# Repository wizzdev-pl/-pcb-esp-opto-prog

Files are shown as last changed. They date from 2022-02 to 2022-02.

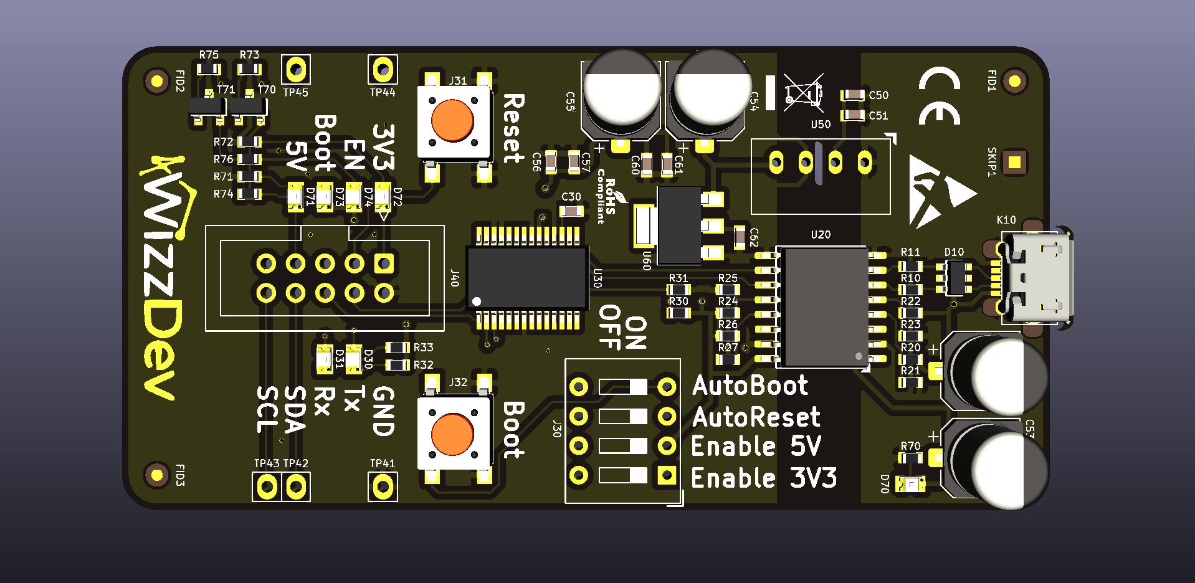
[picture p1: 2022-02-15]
Doc/EspOptoProg HV2 220111/EspOptoProg HV2 220111 Images/02 top.jpg

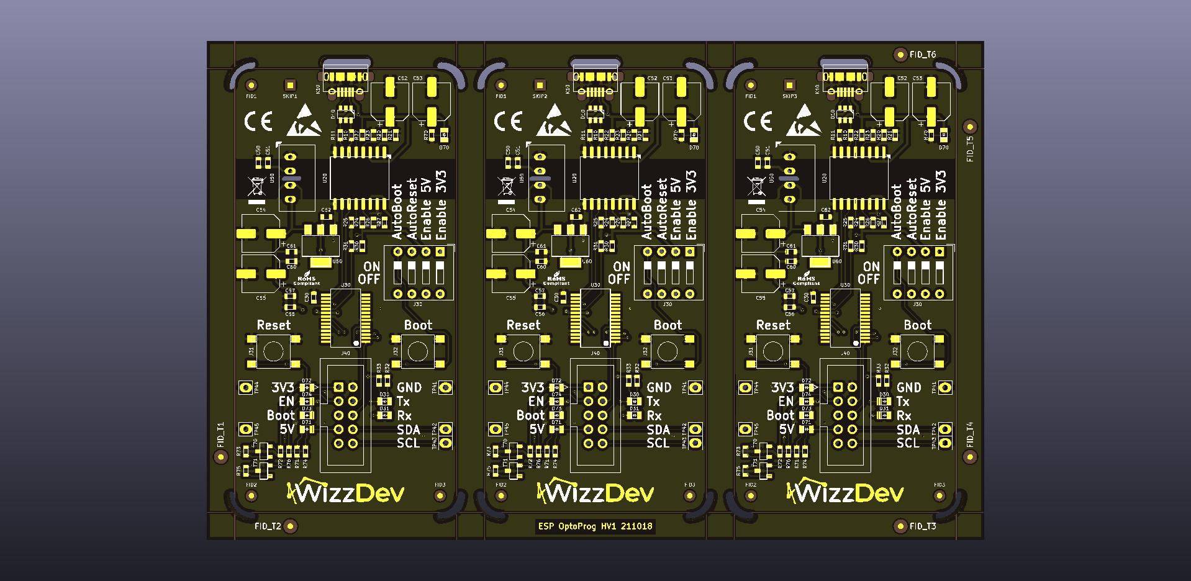
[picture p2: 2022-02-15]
Doc/EspOptoProg HV2 220111/EspOptoProg HV2 220111 Images/11 top.jpg

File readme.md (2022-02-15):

# ESP Optoisolated Programmer

This repo contains design files of the ESP Optoisolated Programmer. It is helpful to develop software for products with and ESP microcontroller that are powered from 230V mains. It works for ESP32, ESP8266 and all other ESP modules.

For detailed description please read:
- [Schematic Description 1](https://wizzdev.pl/blog/esp32-optoisolated-programmer-schematic-description-1/)
- [Schematic Description 2](https://wizzdev.pl/blog/esp32-optoisolated-programmer-schematic-description-2/)
- [PCB Analysis 1](https://wizzdev.pl/blog/esp32-optoisolated-programmer-pcb-analysis-1-2/)
- [PCB Analysis 2](https://wizzdev.pl/blog/esp32-optoisolated-programmer-pcb-analysis-2/)
- [PCB Analysis 3](https://wizzdev.pl/blog/esp32-optoisolated-programmer-pcb-analysis-3/)

To open and edit design files, please use Kicad 6.

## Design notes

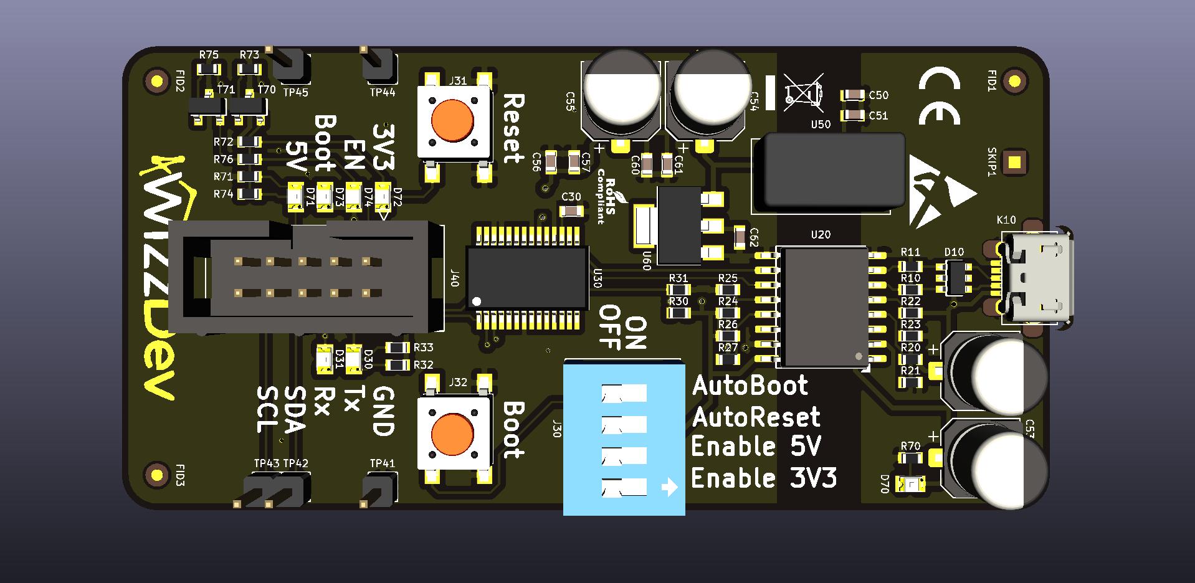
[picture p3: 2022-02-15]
Doc/EspOptoProg HV2 220111/EspOptoProg HV2 220111 Images/03 top.jpg

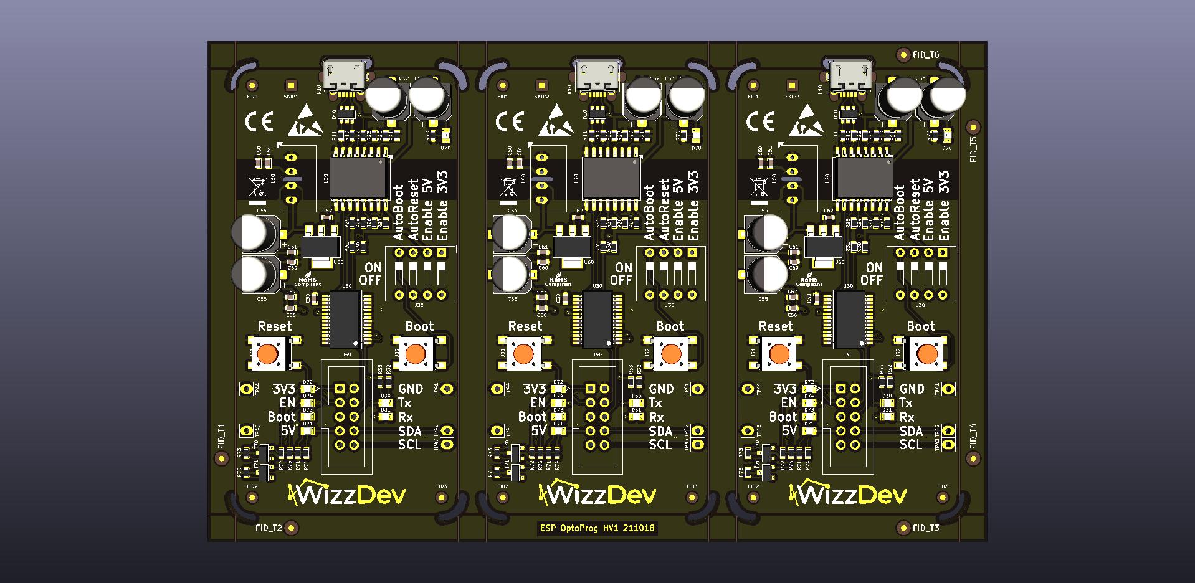
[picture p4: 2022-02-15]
Doc/EspOptoProg HV2 220111/EspOptoProg HV2 220111 Images/12 top.jpg

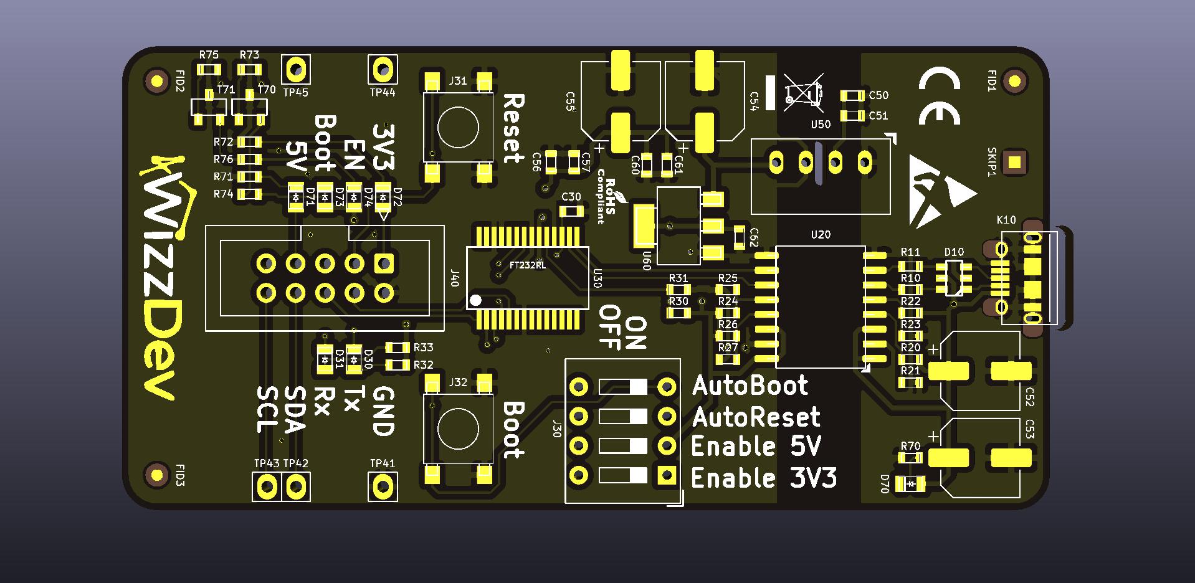
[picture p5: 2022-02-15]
Doc/EspOptoProg HV2 220111/EspOptoProg HV2 220111 Images/01 top.jpg

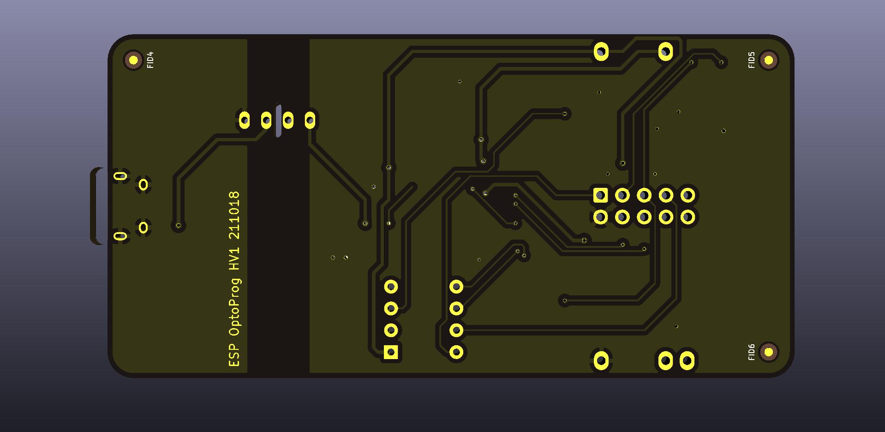
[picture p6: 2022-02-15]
Doc/EspOptoProg HV2 220111/EspOptoProg HV2 220111 Images/04 bottom.jpg

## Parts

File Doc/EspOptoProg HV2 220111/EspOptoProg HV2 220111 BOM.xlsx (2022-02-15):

Id | Ref | Package | Qty | Value | Comment | Link / part number
1 | U50 | AMxS-xxxxSZ | 1 | AM2S-0505SZ | Converter: DC/DC; 2W; Uin: 4.5÷5.5V; Uout: 5VDC; Iout: 400mA; SIP4
2 | C21,C20,C57,C62,C61,C50,C30 | C_0603 | 7 | 100n | Voltage min 25V, Tolerance 25%, X7R
5 | U20 | SOIC-16W_7.5x10.3mm_P1.27mm | 1 | ADUM3160 | IC: interface; digital isolator; 12Mbps; iCoupler®; 3÷5.5VDC; USB
7 | U30 | ssop-28 | 1 | FT232RL | IC: interface; USB-UART; Full Speed; 3.3÷5VDC; reel; SSOP28
8 | C53,C55,C54,C52 | CP_Elec_6.3x7.7 | 4 | 220u | Capacitor: electrolytic; SMD; 220uF; 10VDC; Ø6.3x7.7mm; ±20%; 2000h | https://www.tme.eu/pl/en/details/sc1a227m6l07kvr/85degc-smd-electrolytic-capacitors/samwha/
9 | J30 | SW_DIP_SPSTx04_Slide_9.78x12.34mm_W7.62mm_P2.54mm | 1 | DIPSW4 | Switch: DIP-SWITCH; Poles number: 4; ON-OFF; 0.1A/24VDC; Pos: 2 | https://www.tme.eu/pl/en/details/eah104e/dip-switches/diptronics/ndi-04h-v/
10 | J40 | IDC-Header_2x05_P2.54mm_Vertical | 1 | IDC-10 | Pin header; pin strips; male; PIN: 10; straight; 2.54mm; THT; 2x5
11 | C56,C51 | C_0603 | 2 | 10u | Voltage min 25V, Tolerance 25%, X7R
14 | T71,T70 | SOT23 | 2 | BC857 | Transistor: PNP; bipolar; 45V; 0.1A; 0.25W; SOT23
16 | R76,R74,R33,R32 | R_0603 | 4 | 100R | Tolerance 5%, Voltage min 25V, Power min 0.1W
17 | R75,R73,R31 | R_0603 | 3 | 10k | Tolerance 5%, Voltage min 25V, Power min 0.1W
18 | D74,D73 | LED_0805 | 2 | OF-SMD2012Y | LED; SMD; 0805; yellow; 210÷270mcd; 2x1.25x0.68mm; 120°; 1.8÷2V
22 | U60 | SOT223 | 1 | 1117-3.3 | Linear regulator, Output 3.3V, Current 1A, Package SOT223
23 | R72 | R_0603 | 1 | 1k | Tolerance 5%, Voltage min 25V, Power min 0.1W
24 | R71,R70 | R_0603 | 2 | 2k2 | Tolerance 5%, Voltage min 25V, Power min 0.1W
25 | R30 | R_0603 | 1 | 4k7 | Tolerance 5%, Voltage min 25V, Power min 0.1W
26 | R11,R10 | R_0603 | 2 | 22R | Tolerance 5%, Voltage min 25V, Power min 0.1W
27 | K10 | USB_Micro_B_Amphenol_10118194-0001LF_PIP | 1 | USB | Socket; USB B micro; on PCBs; SMT,THT; PIN: 5; horizontal; USB 2.0 | https://www.tme.eu/pl/en/details/10118194-0001lf_c/usb-ieee1394-connectors/amphenol-icc/10118194-0001lf/
28 | J32,J31 | TACT_6x6_SMD | 2 | TACT_6x6_SMD | Microswitch TACT; SPST-NO; Pos: 2; 0.05A/12VDC; SMT; none; 1.6N | https://www.tme.eu/pl/en/details/tactm-69n-f/microswitches-tact/ninigi/
34 | D72,D71,D70 | LED_0805 | 3 | OF-SMD2012W | LED; SMD; 0805; white cold; 1000÷1400mcd; 6500K; 120°; 20mA
35 | D31 | LED_0805 | 1 | OF-SMD2012G | LED; SMD; 0805; green; 50÷100mcd; 2x1.25x0.68mm; 120°; 1.8÷2V; 20mA
36 | D30 | LED_0805 | 1 | OF-SMD2012R | LED; SMD; 0805; red; 90÷120mcd; 2x1.25x0.68mm; 120°; 1.6÷1.9V; 20mA
37 | D10 | SOT23-6 | 1 | USBLC6-2 | Diode: TVS array; 6V; bidirectional; SOT23-6; Package: reel,tape
38 | C60 | C_0603 | 1 | 1u | Voltage min 25V, Tolerance 25%, X7R

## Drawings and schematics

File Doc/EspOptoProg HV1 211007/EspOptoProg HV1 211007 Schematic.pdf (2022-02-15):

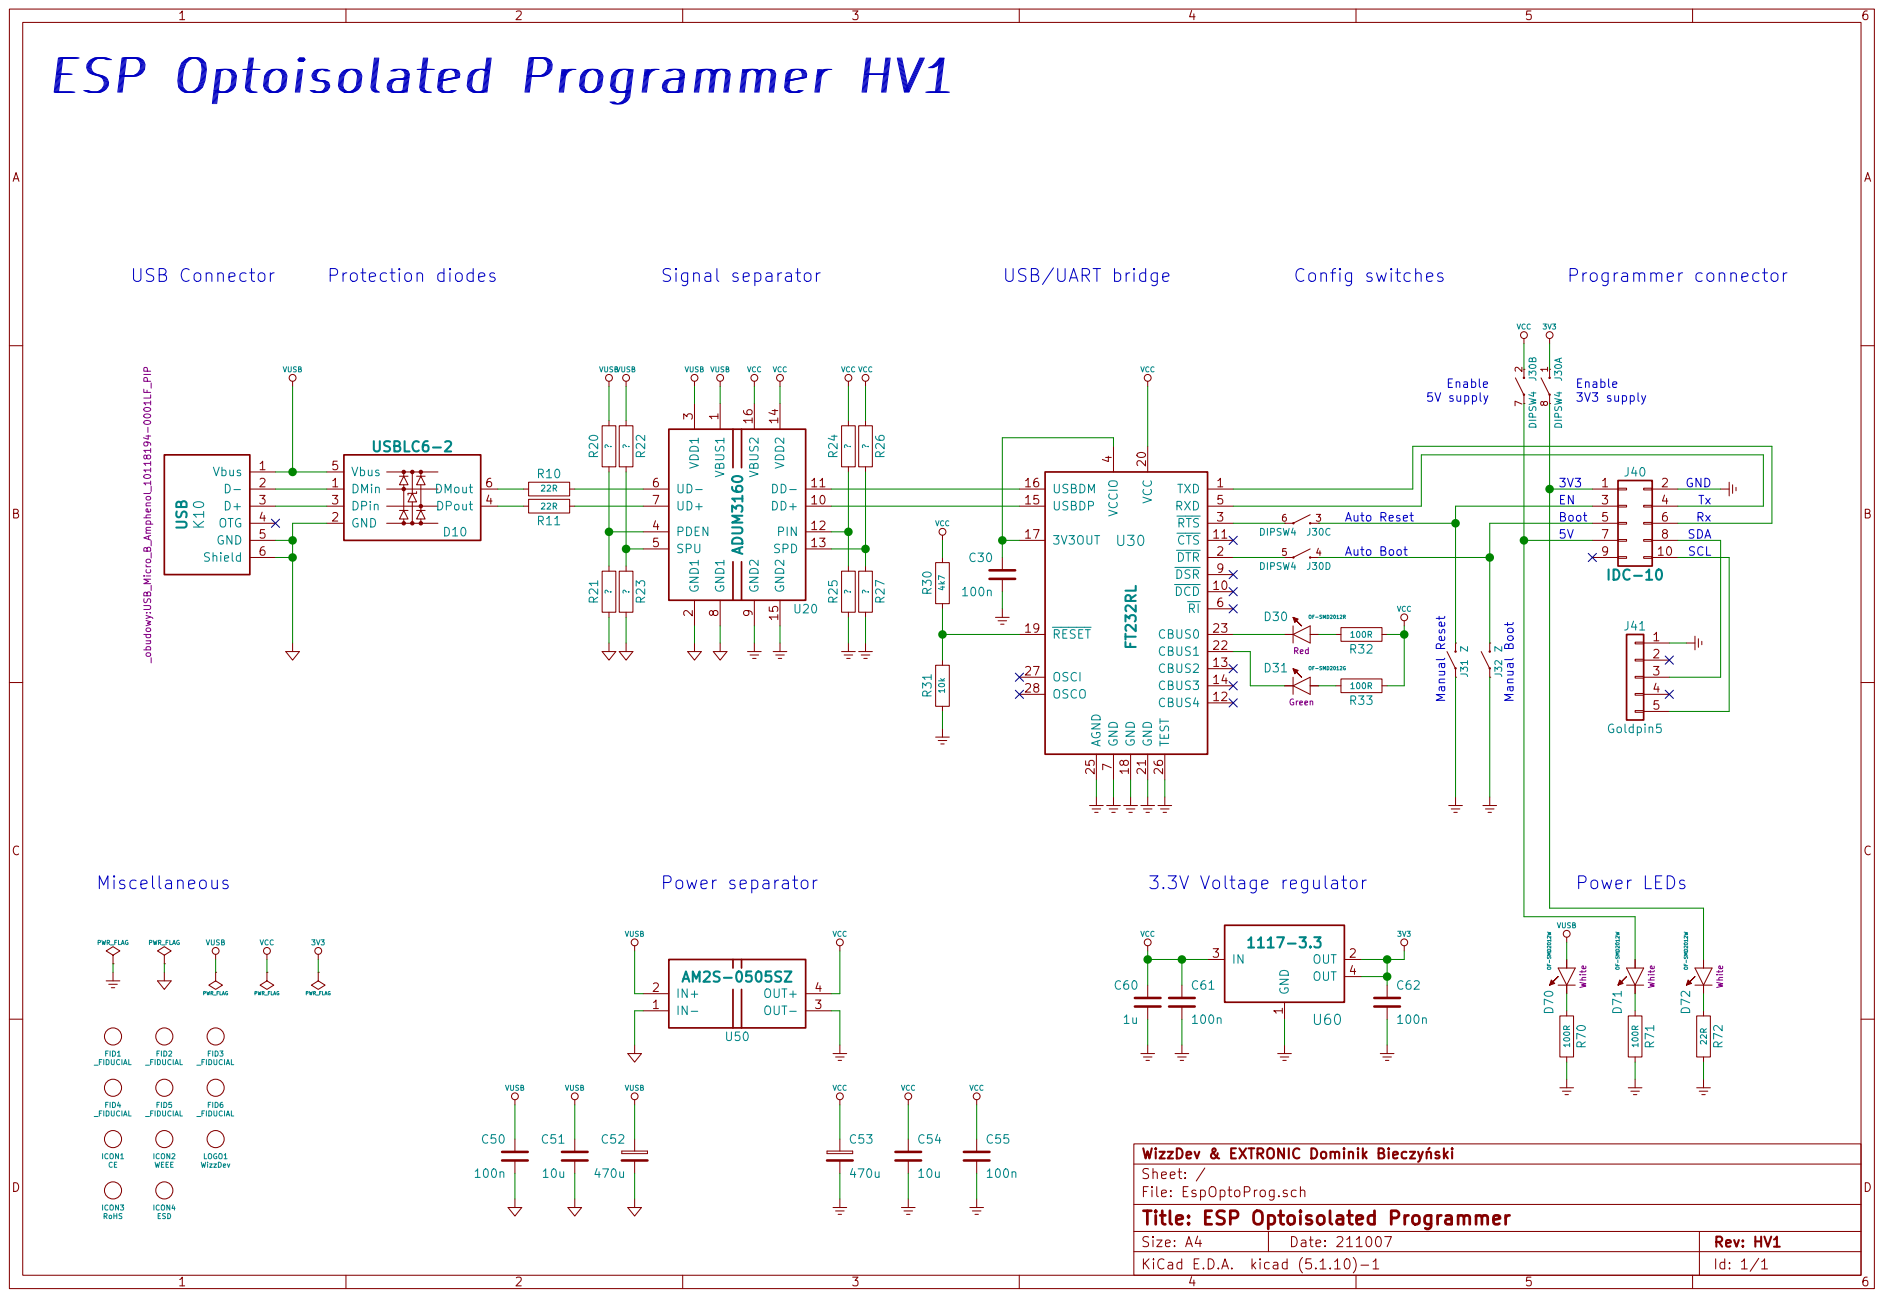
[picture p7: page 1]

3 PDEN 4 SPU 5 UD- 6 UD+ 7 GND1

1 DD+ 10 DD- 11 PIN 12 SPD 13 VDD2 14 GND2 15 VBUS2 16 GND1

Boot EN 3 | 4

File: EspOptoProg.sch Sheet: / WizzDev & EXTRONIC Dominik Bieczyski C50

Id: 1/1 Title: ESP Optoisolated Programmer

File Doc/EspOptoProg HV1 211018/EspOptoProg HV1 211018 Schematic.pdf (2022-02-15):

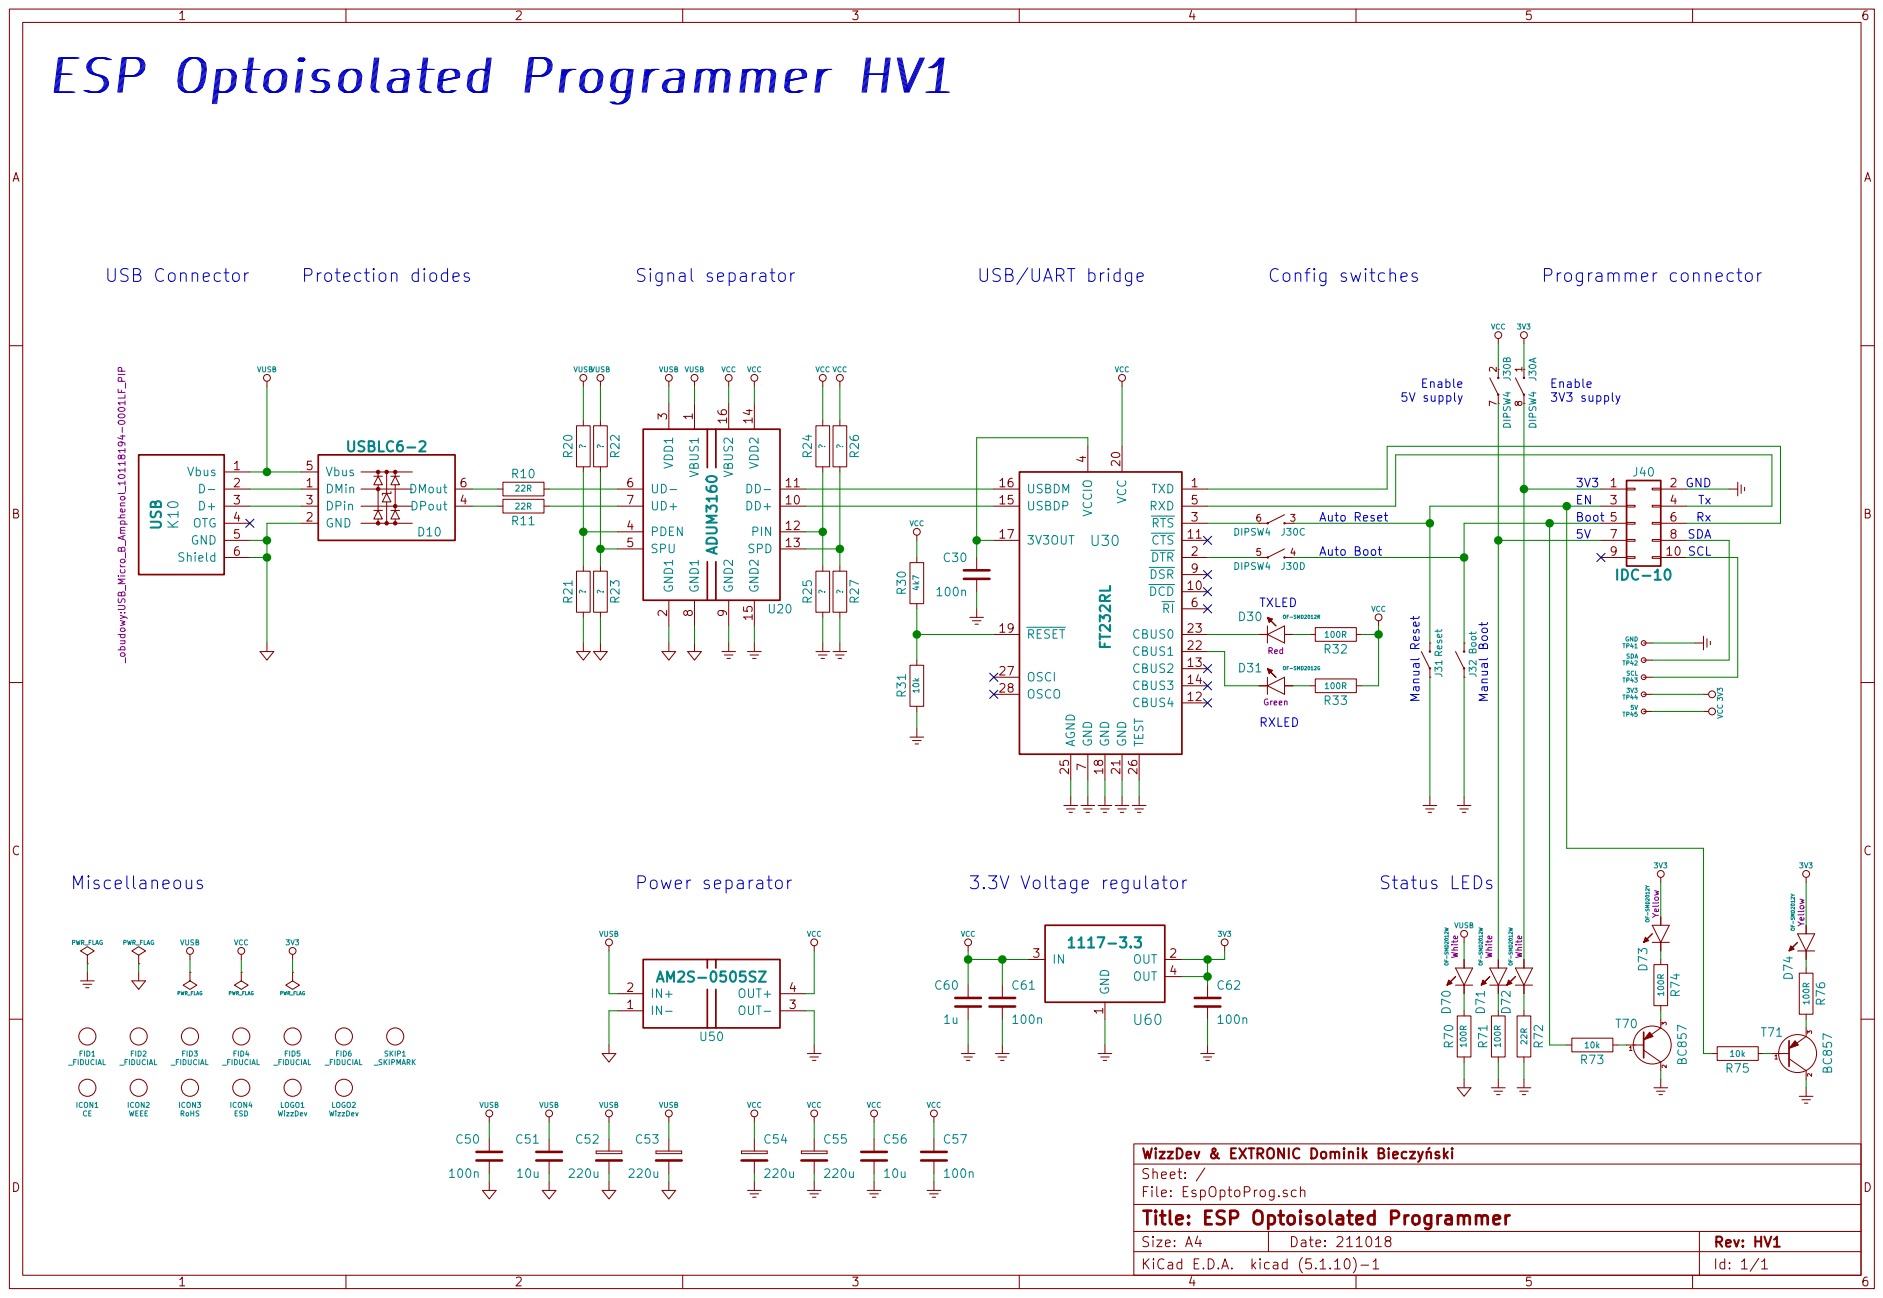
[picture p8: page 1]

5V supply Auto Boot Auto Reset ESP Optoisolated Programmer HV1

3 PDEN 4 SPU 5 UD- 6 UD+ 7 GND1

1 DD+ 10 DD- 11 PIN 12 SPD 13 VDD2 14 GND2 15 VBUS2 16 GND1

File: EspOptoProg.sch Sheet: / WizzDev & EXTRONIC Dominik Bieczyski R26? VCC

VCC | 6 3 DIPSW4 J30C | Boot 5V 5 | 6

Id: 1/1 Title: ESP Optoisolated Programmer

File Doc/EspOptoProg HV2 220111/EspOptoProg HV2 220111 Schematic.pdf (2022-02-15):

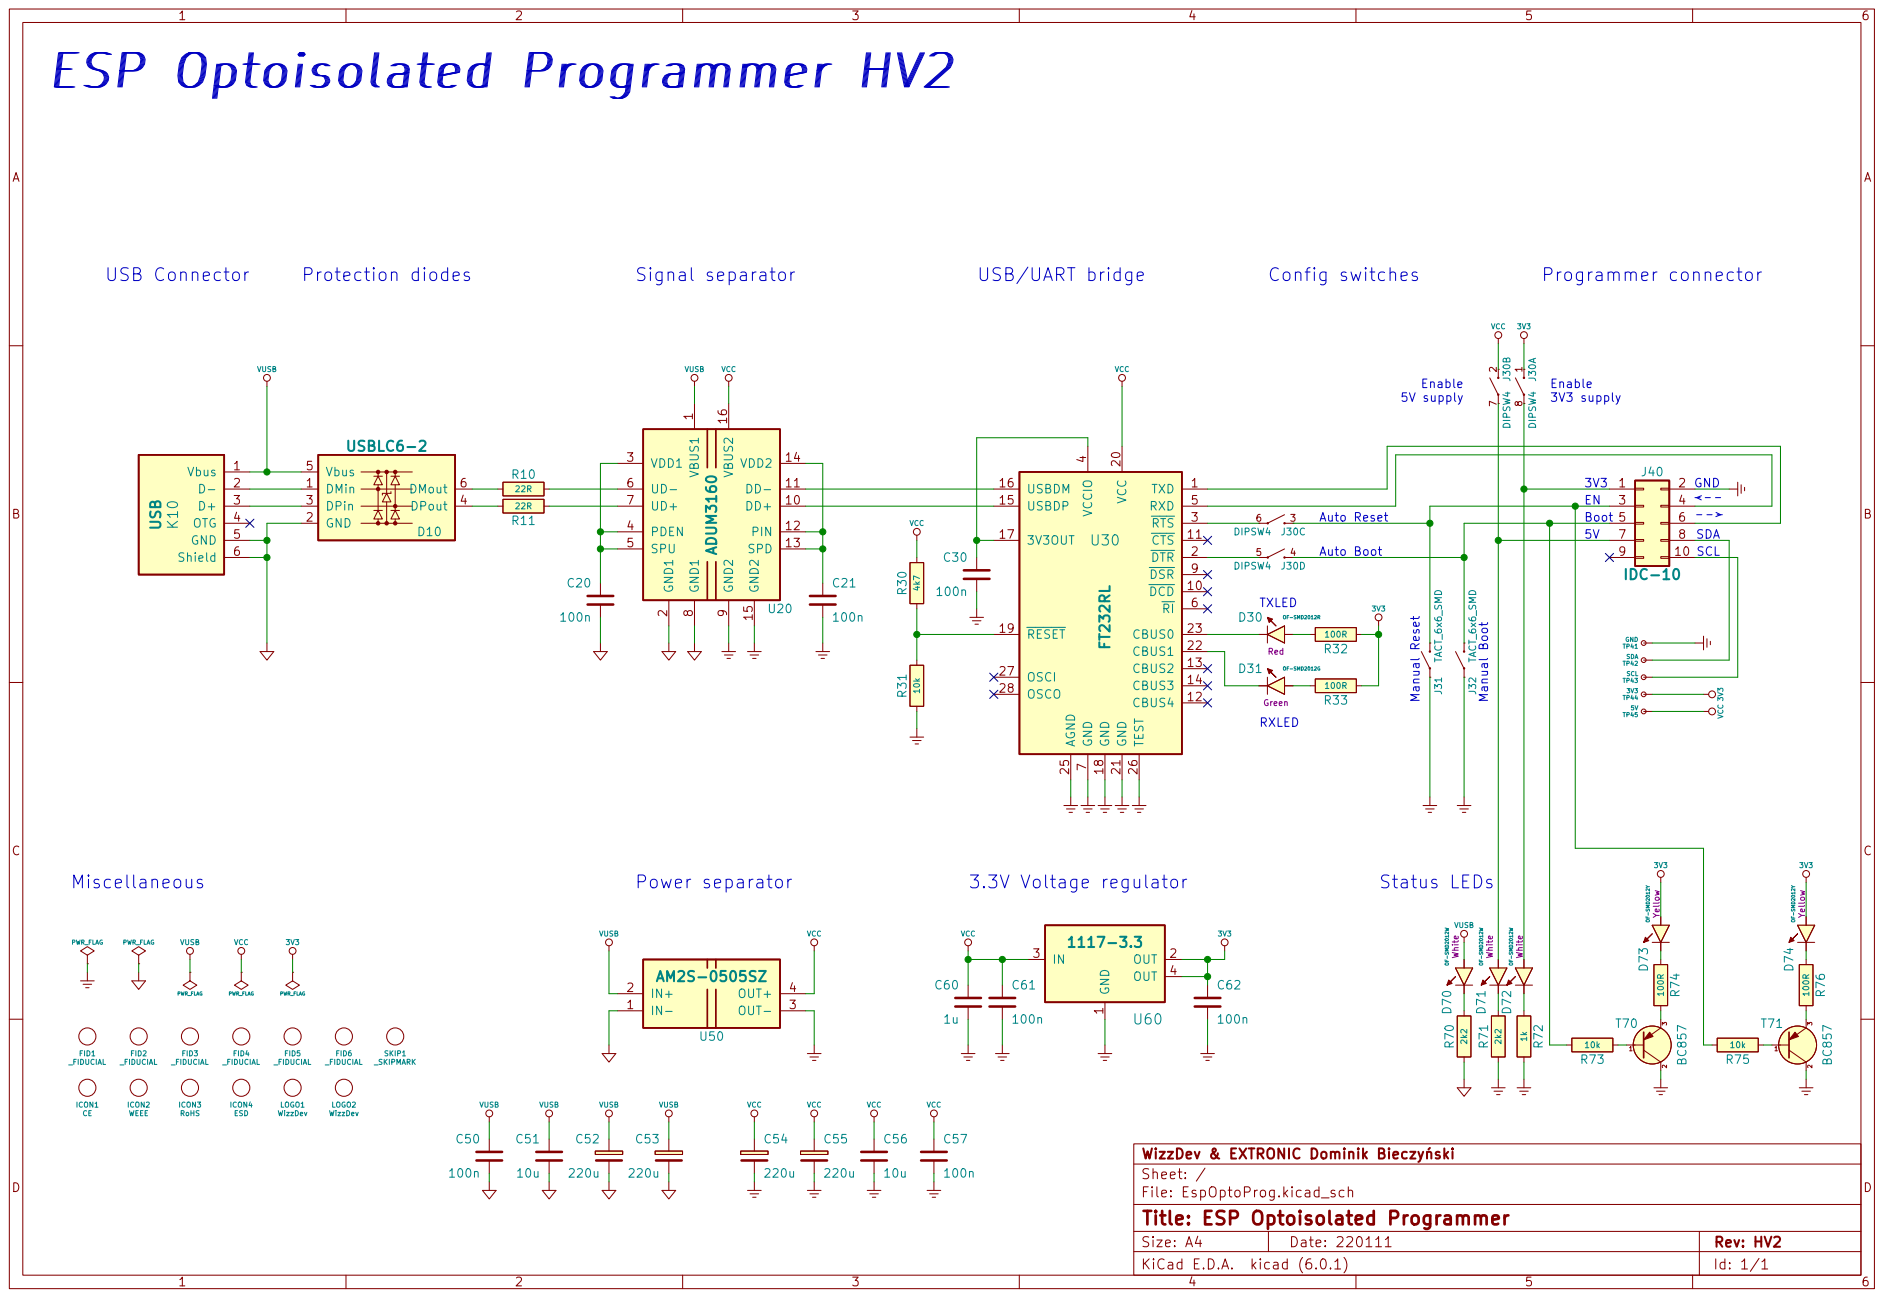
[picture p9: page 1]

1 DD+ 10 DD- 11 PIN 12 SPD 13 VDD2 14 GND2 15 VBUS2 16 GND1

2 VDD1 3 PDEN 4 SPU 5 UD- 6 UD+ 7 GND1

File: EspOptoProg.kicad_sch Sheet: / þÿWizzDev & EXTRONIC Dominik BieczyDski 3V3

Id: 1/1 Title: ESP Optoisolated Programmer

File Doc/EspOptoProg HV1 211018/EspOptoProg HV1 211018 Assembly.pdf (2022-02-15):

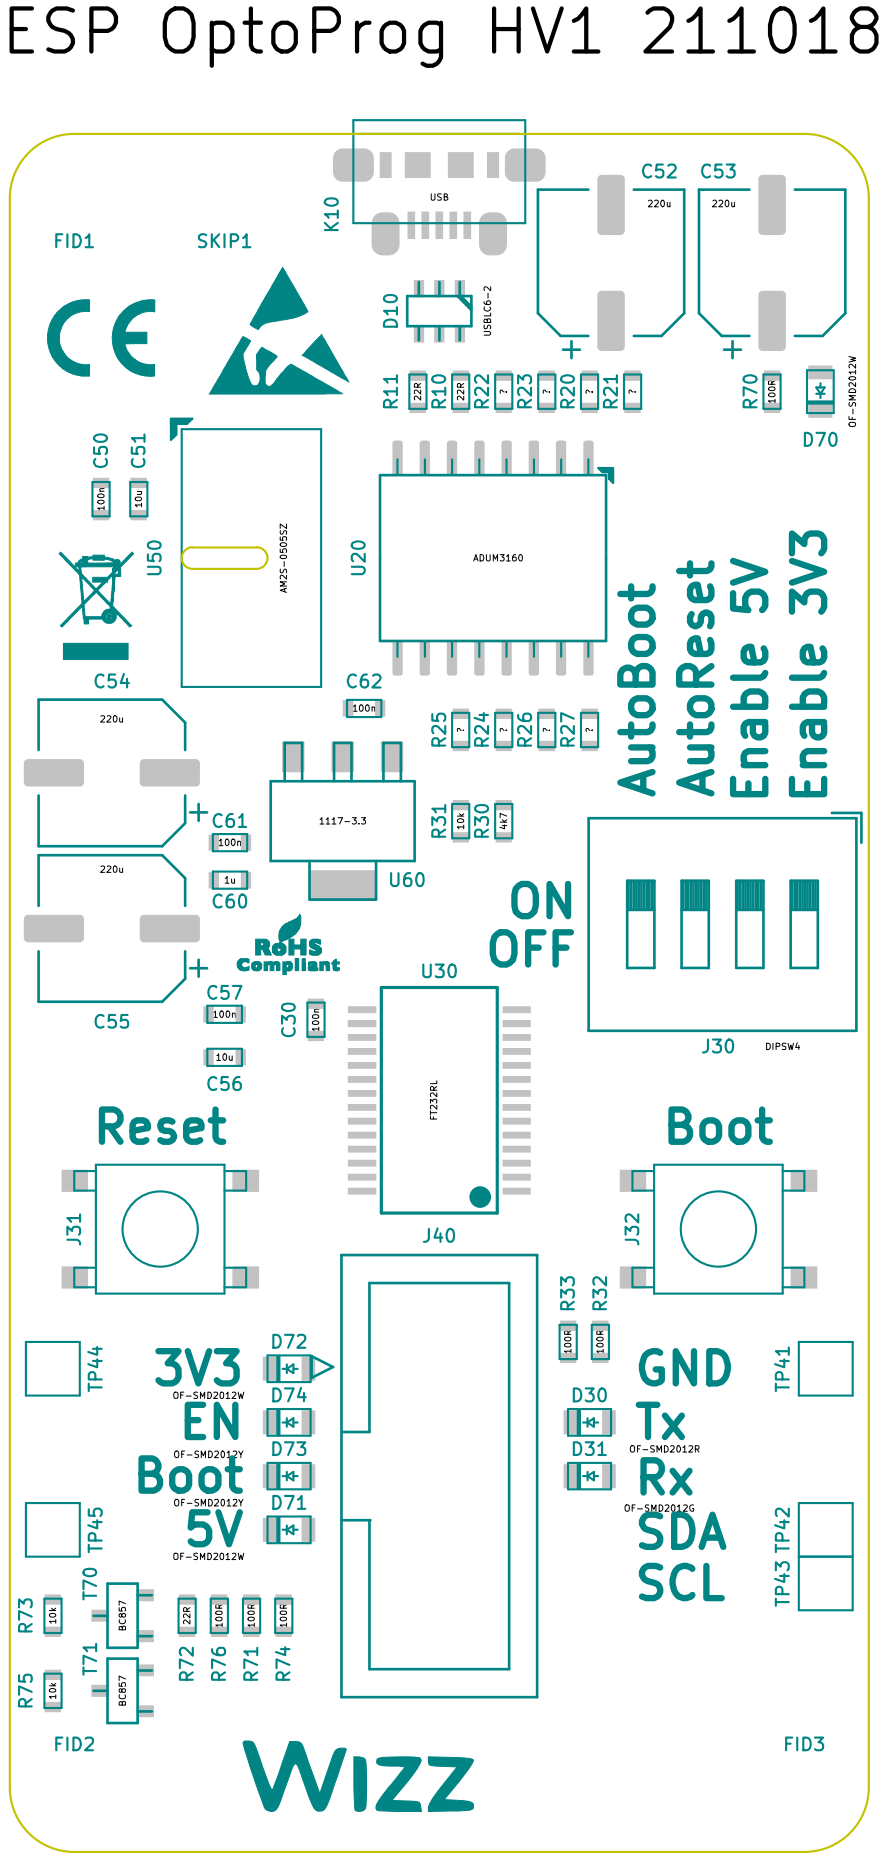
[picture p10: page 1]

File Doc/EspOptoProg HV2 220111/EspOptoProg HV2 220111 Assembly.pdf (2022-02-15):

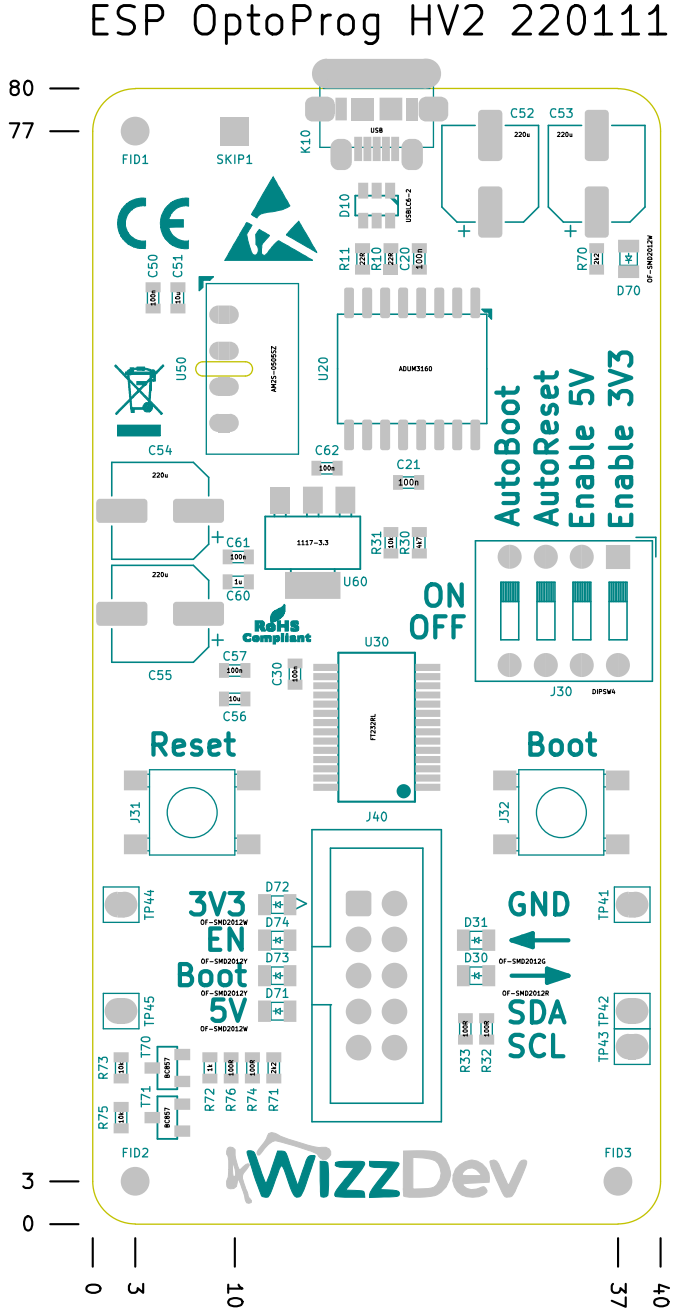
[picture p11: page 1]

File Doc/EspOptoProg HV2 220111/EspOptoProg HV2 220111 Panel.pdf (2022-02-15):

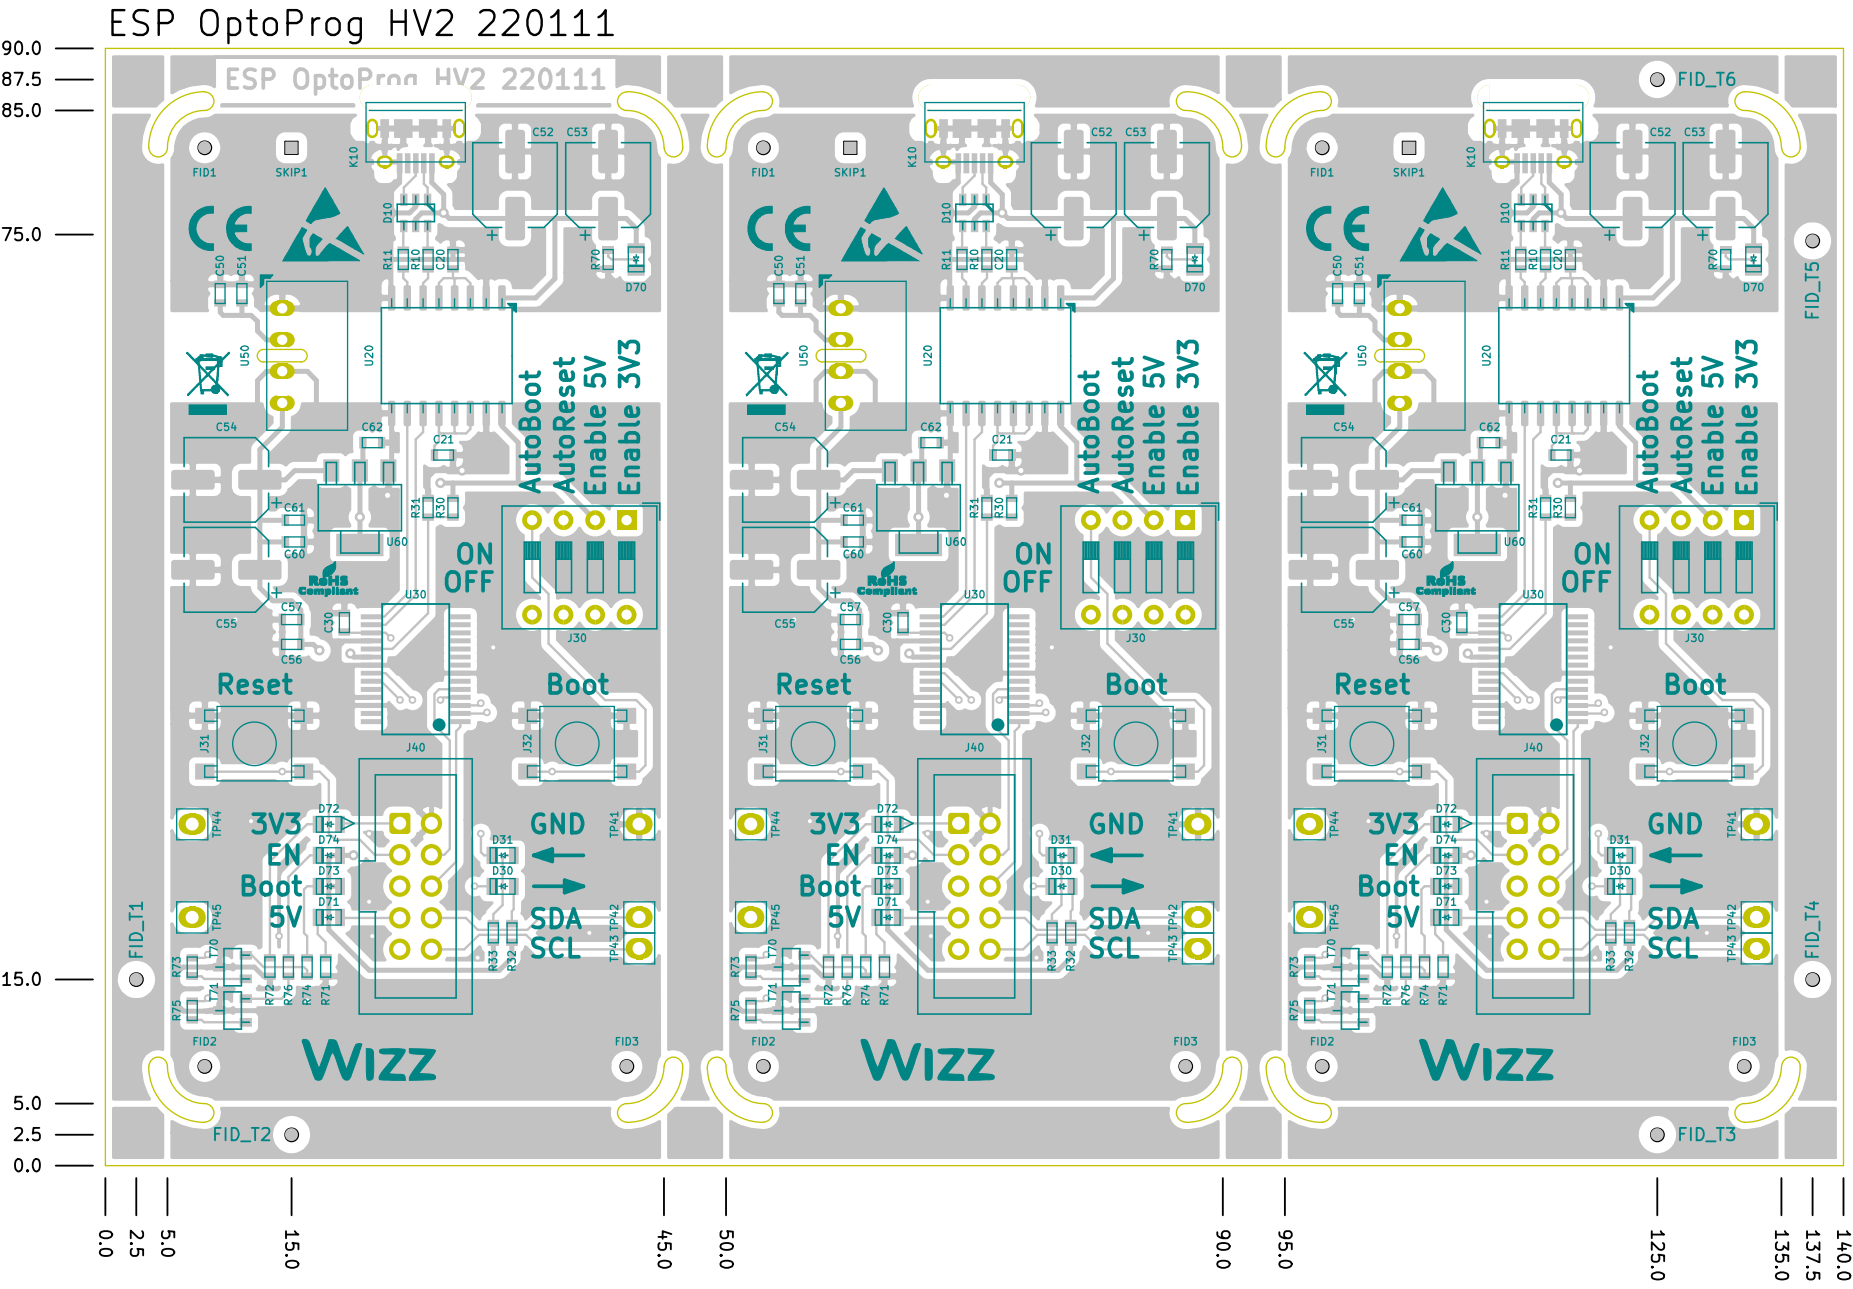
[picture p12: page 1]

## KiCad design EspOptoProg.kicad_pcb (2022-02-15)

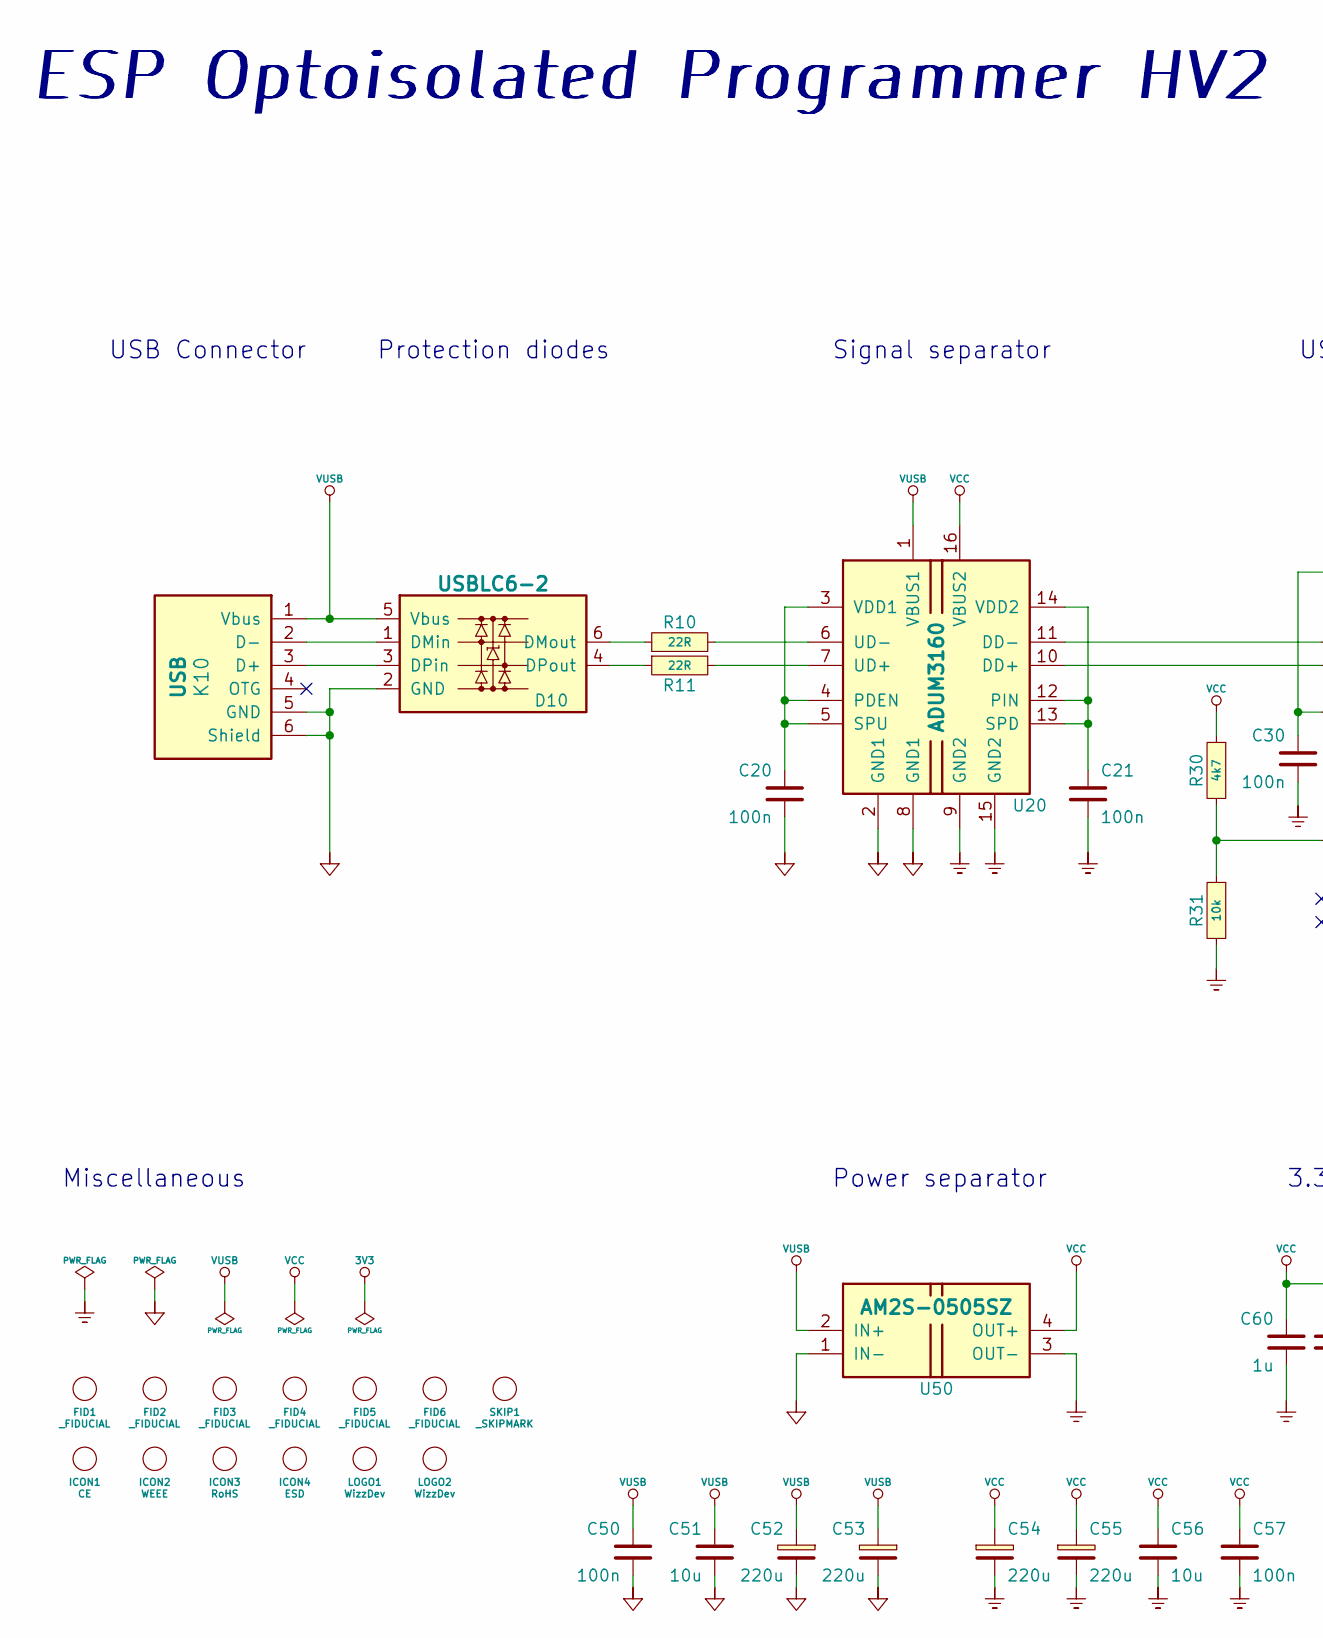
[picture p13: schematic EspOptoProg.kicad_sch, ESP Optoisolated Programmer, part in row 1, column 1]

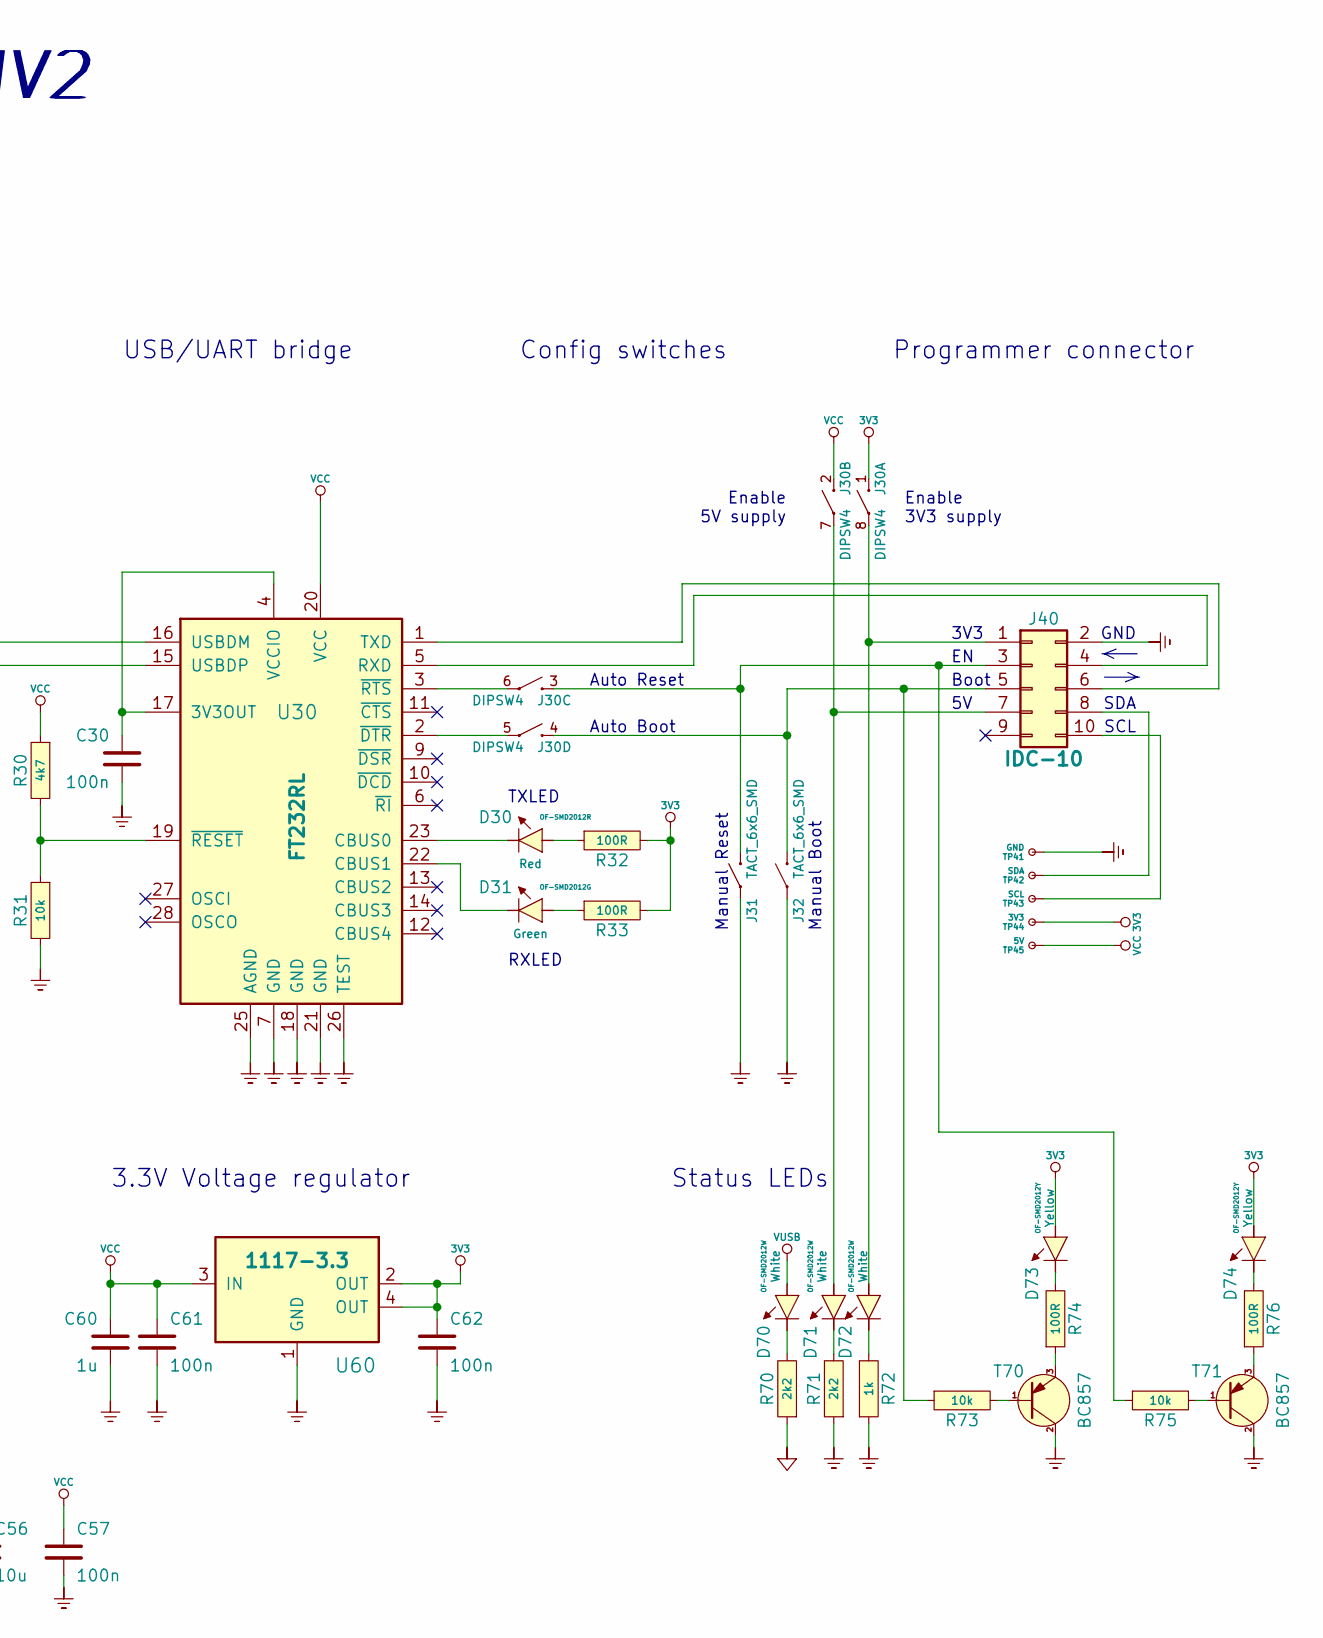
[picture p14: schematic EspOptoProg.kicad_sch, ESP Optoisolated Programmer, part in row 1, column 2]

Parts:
C20, C21, C30, C50, C57, C61, C62: 100n; C_0603
C51, C56: 10u; C_0603
C52, C53, C54, C55: 220u; CP_Elec_6.3x7.7; Part SC1A227M6L07KVR SAMWHA
C60: 1u; C_0603
D10: USBLC6-2; SOT23-6
D30: OF-SMD2012R; LED_0805; Part OF-SMD2012R OPTOFLASH
D31: OF-SMD2012G; LED_0805; Part OF-SMD2012G OPTOFLASH
D70, D71, D72: OF-SMD2012W; LED_0805; Part OF-SMD2012W OPTOFLASH
D73, D74: OF-SMD2012Y; LED_0805
FID1, FID2, FID3, FID4, FID5, FID6: _FIDUCIAL; Fiducial_1.00mm_ring0.5mm
ICON1: CE; Logo_silk_CE_5x3.6mm
ICON2: WEEE; Logo_silk_WEEE_3.4x5mm
ICON3: RoHS; Logo_silk_ROHS_5x2.8mm
ICON4: ESD; ESD-Logo_6.6x6mm_SilkScreen
J30: DIPSW4; SW_DIP_SPSTx04_Slide_9.78x12.34mm_W7.62mm_P2.54mm; Part NDI-04H-V DIPTRONICS
J31, J32: TACT_6x6_SMD; Part TACTM-69N-F NINIGI
J40: IDC-10; IDC-Header_2x05_P2.54mm_Vertical
K10: USB; USB_Micro_B_Amphenol_10118194-0001LF_PIP; Part 10118194-0001LF
LOGO1: WizzDev; wizzdev-logo-part1
LOGO2: WizzDev; wizzdev-logo-part2
R10, R11: 22R; R_0603
R30: 4k7; R_0603
R31, R73, R75: 10k; R_0603
R32, R33, R74, R76: 100R; R_0603
R70, R71: 2k2; R_0603
R72: 1k; R_0603
SKIP1: _SKIPMARK; Skipmark_1.00mm
T70, T71: BC857; SOT23
TP41: GND; 1pin
TP42: SDA; 1pin
TP43: SCL; 1pin
TP44: 3V3; 1pin
TP45: 5V; 1pin
U20: ADUM3160; SOIC-16W_7.5x10.3mm_P1.27mm
U30: FT232RL; ssop-28
U50: AM2S-0505SZ; AMxS-xxxxSZ
U60: 1117-3.3; SOT223; Part 1117-3.3

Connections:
3V3: C62.1, D73.2 (A), D74.2 (A), J30.1, R32.2, R33.2, TP44.1, U60.2 (OUT), U60.4 (OUT)
GND: C21.2, C30.2, C54.2, C55.2, C56.2, C57.2, C60.2, C61.2, C62.2, J31.2, J32.2, J40.2, R31.2, R71.1, R72.1, T70.2, T71.2, TP41.1, U20.9 (GND2), U20.15 (GND2), U30.7 (GND), U30.18 (GND), U30.21 (GND), U30.25 (AGND), U30.26 (TEST), U50.3 (OUT-), U60.1 (GND)
GND2: C20.2, C50.2, C51.2, C52.2, C53.2, D10.2 (GND), K10.5 (GND), K10.6 (Shield), R70.1, U20.2 (GND1), U20.8 (GND1), U50.1 (IN-)
unnamed: C20.1, U20.3 (VDD1), U20.4 (PDEN), U20.5 (SPU)
unnamed: C21.1, U20.12 (PIN), U20.13 (SPD), U20.14 (VDD2)
unnamed: C30.1, U30.4 (VCCIO), U30.17 (3V3OUT)
unnamed: D10.1 (DMin), K10.2 (D-)
unnamed: D10.3 (DPin), K10.3 (D+)
unnamed: D10.4 (DPout), R11.1
unnamed: D10.6 (DMout), R10.1
unnamed: D30.1 (K), U30.23 (CBUS0)
unnamed: D30.2 (A), R32.1
unnamed: D31.1 (K), U30.22 (CBUS1)
unnamed: D31.2 (A), R33.1
unnamed: D70.1 (K), R70.2
unnamed: D71.1 (K), R71.2
unnamed: D71.2 (A), J30.7, J40.7
unnamed: D72.1 (K), R72.2
unnamed: D72.2 (A), J30.8, J40.1
unnamed: D73.1 (K), R74.2
unnamed: D74.1 (K), R76.2
unnamed: J30.3, J31.1, J40.3, R75.1
unnamed: J30.4, J32.1, J40.5, R73.1
unnamed: J30.5, U30.2 (~DTR)
unnamed: J30.6, U30.3 (~RTS)
unnamed: J40.4, U30.5 (RXD)
unnamed: J40.6, U30.1 (TXD)
unnamed: J40.8, TP42.1
unnamed: J40.10, TP43.1
unnamed: R10.2, U20.6 (UD-)
unnamed: R11.2, U20.7 (UD+)
unnamed: R30.2, R31.1, U30.19 (~RESET)
unnamed: R73.2, T70.1
unnamed: R74.1, T70.3
unnamed: R75.2, T71.1
unnamed: R76.1, T71.3
unnamed: U20.10 (DD+), U30.15 (USBDP)
unnamed: U20.11 (DD-), U30.16 (USBDM)
VCC: C54.1, C55.1, C56.1, C57.1, C60.1, C61.1, J30.2, R30.1, TP45.1, U20.16 (VBUS2), U30.20 (VCC), U50.4 (OUT+), U60.3 (IN)
VUSB: C50.1, C51.1, C52.1, C53.1, D10.5 (Vbus), D70.2 (A), K10.1 (Vbus), U20.1 (VBUS1), U50.2 (IN+)

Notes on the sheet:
SCL
ESP Optoisolated Programmer HV2
Signal separator
3.3V Voltage regulator
Auto Reset
USB/UART bridge
Enable 3V3 supply
Manual Boot
Enable 5V supply
Status LEDs
3V3
Boot
Manual Reset
Miscellaneous
Power separator
RXLED
GND
Auto Boot
Protection diodes
Programmer connector
Config switches
USB Connector
TXLED
SDA

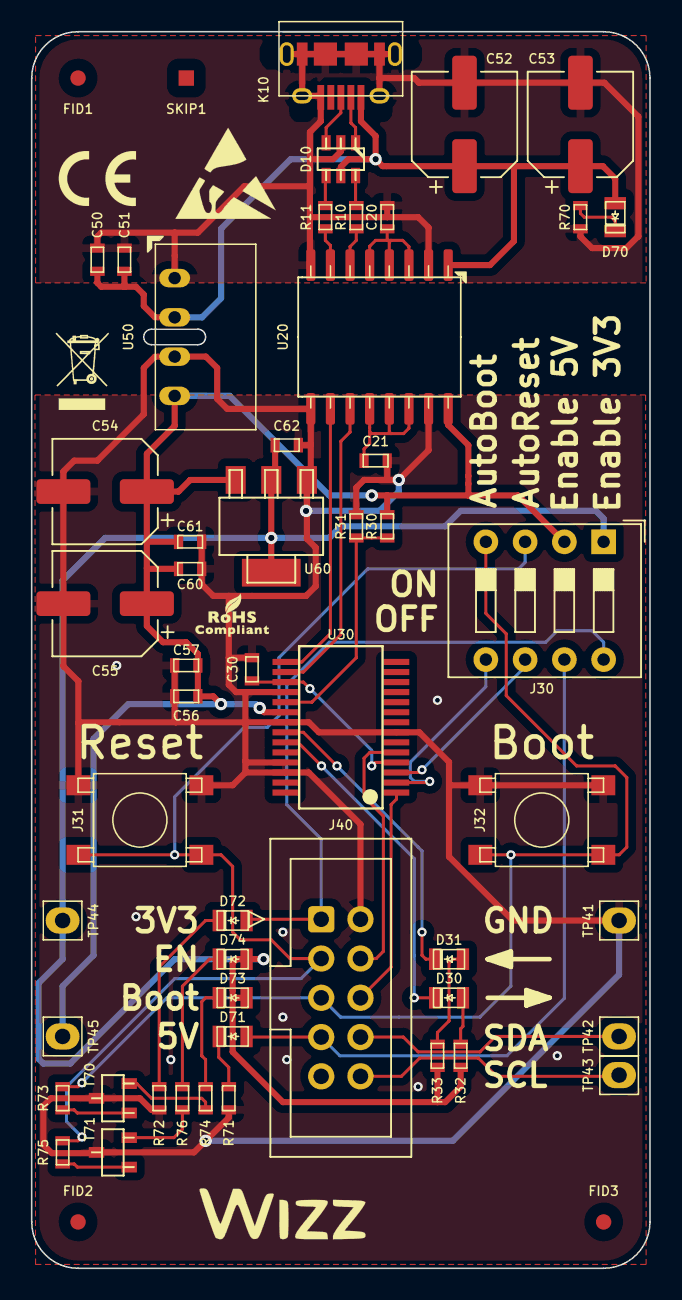
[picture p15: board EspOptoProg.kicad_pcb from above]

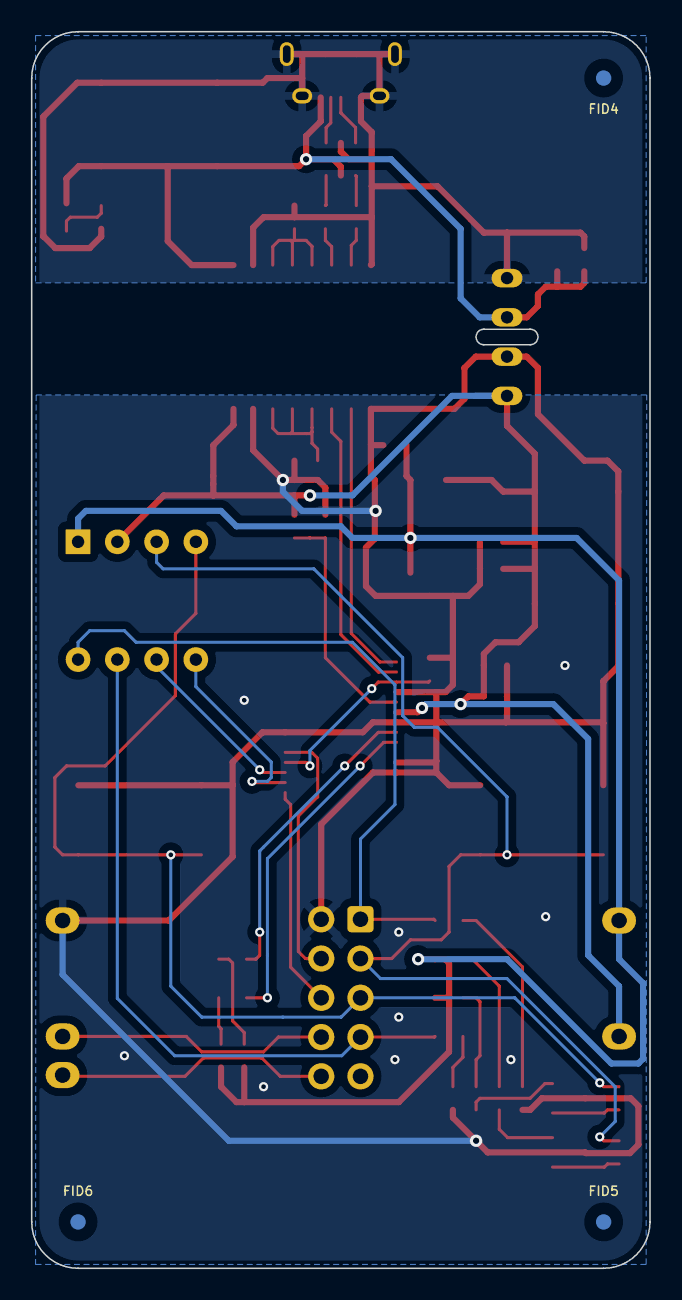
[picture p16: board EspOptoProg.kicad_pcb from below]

Board: 2 copper layers, 40.0 x 80.0 mm, 64 parts (3 on the bottom side), 40 nets.
